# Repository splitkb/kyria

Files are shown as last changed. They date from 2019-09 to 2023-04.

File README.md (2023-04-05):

# Kyria

The Kyria is a split keyboard kit by Thomas Baart of [splitkb.com](https://splitkb.com). In this repository you'll find files you can use to make your own Kyria case.

THE SOFTWARE IS PROVIDED "AS IS", WITHOUT WARRANTY OF ANY KIND, EXPRESS OR IMPLIED, INCLUDING BUT NOT LIMITED TO THE WARRANTIES OF MERCHANTABILITY, FITNESS FOR A PARTICULAR PURPOSE AND NONINFRINGEMENT. IN NO EVENT SHALL THE AUTHORS OR COPYRIGHT HOLDERS BE LIABLE FOR ANY CLAIM, DAMAGES OR OTHER LIABILITY, WHETHER IN AN ACTION OF CONTRACT, TORT OR OTHERWISE, ARISING FROM, OUT OF OR IN CONNECTION WITH THE SOFTWARE OR THE USE OR OTHER DEALINGS IN THE SOFTWARE.

These files are available for non-commercial use only. You explicitly have permission to make objects with these files for yourself, friends, family and coworkers. If you'd like to sell objects made from these files, please [get in touch](mailto:support@splitkb.com?subject=Aurora%20case%20licensing).

## Which files do I need?

1. Look for the folder of your keyboard, depending on your revision.
2. Decide whether you need kerf (see below: What's kerf?).
3. Pick the files for your keyboard:
    - **A bottom plate**: We have normal plates and puck plates. A normal plate is a fully covered plate, whereas a puck plate is compatible with the splitkb.com [Tenting Puck](https://splitkb.com/products/tenting-puck). It has a circular slot cut out for the puck to sit into. Bottom plates can easily be replaced later, so feel free to get a normal plate if you don't have a puck yet.
    - **A top plate**: We have normal plates, no puck plates and encoder plates. Normal plates have mounting holes, holes for switches, and holes for the puck screws to be mounted through. I recommend getting the normal plates, as the extra holes don't impact functionality and make it easier to add a puck later. The "no puck" plates don't have these extra mounting holes, and the "encoder" plates have wider holes for when you want to use an encoder on a choc-based build. You'll likely want to modify the encoder files before using them, as an encoder hole is larger and won't allow a switch to clip into the plate.
    - **An OLED cover**: Most keyboards will support OLED covers. They protect the microcontroller and display area. Even if you don't use an OLED, I still recommend using a cover, as it'll make the keyboard look more finished. If your keyboard doesn't have a file with "OLED Cover" in its name, then a cover isn't supported.

For rev1 and rev2 boards, a high profile case is available. The case composition and required hardware is a little different there, and is not supported for rev3 for the time being.

All files are symmetrical, meaning you use the same file for both the left and the right side. When ordering parts, make sure you order two of every file you've selected.

The files in this repository are DXF files, which can be opened using a tool like LibreCAD, Adobe Illustrator or other similar CAD or graphic design software packages. You'll be able to send these to a manufacturer to produce cases with for personal use, or modify them using a tool like Fusion 360 to make your own 3D-printable cases.

## What's kerf?

Kerf is the amount of material that's lost in the process of cutting, for example with a laser or water jet. As the cutter moves along the lines in the file, material is removed from either side of the line. Files that account for kerf, add a little bit of material to the edges of all cut lines to compensate for that lost material.

In short, if you're using a laser cutter yourself, you'll want the files with kerf. If you're sending them off to another service, you should ask them whether to include kerf. And if you're 3D printing, you shouldn't need any kerf, or might even need to remove some extra material depending on your printer and calibration.

The files with kerf that we supply are used with our own laser cutter. Third parties might require different settings. We don't supply those files, so you or the third party may have to modify the files to match their process.

## Which thickness do I need?

It depends! Generally:

- For MX switches, 1.5mm is best for the top plate if the material is sturdy enough. For acrylic, go with 3mm.
- For Choc switches, 1.2mm is best for the top plate if the material is sturdy enough. 1.5mm is also fine, and in most cases this makes it compatible with both MX and Choc. For acrylic, go with 3mm and a hand-solderable kit. **Hot swapping 3mm plates makes for a bad experience.**
- For the bottom plate and OLED cover, thickness doesn't matter a lot. We usually go with 3mm for acrylic.

## Which hardware do I need?

The number and lengths of spacers and screws will depend on the keyboard, the switches you use, and the plate thicknesses you choose. You can get all the hardware and some extras when buying an [Aurora Hardware Kit](https://splitkb.com/products/aurora-low-profile-case-hardware-kit).

We also sell various hardware separately:

- [M2 spacers in various lenghts](https://splitkb.com/products/brass-m2-spacers)
- [M2 screws in various lenghts](https://splitkb.com/products/m2-screws)

Generally:

- For MX switches and a metal top plate, go with 8mm spacers.
- For MX switches and an acrylic top plate, go with 6mm spacers.
- For Choc switches and a metal top plate, go with 6mm spacers.
- For Choc switches and an acrylic top plate, go with 4mm spacers.

The OLED cover requires 12mm spacers when using a display, though you might get away with 10mm in some cases. If you don't use a display, you can use 8mm or maybe even 6mm spacers.

## What should I keep in mind?

To prevent disappointment, take care of the following:

- Make sure of some measurements beforehand. For files without kerf, the size of a switch hole will be exactly 14x14mm. For files with kerf, the size of a switch hole will be exactly 13.9x13.9mm.
- Only use plates thicker than 1.6mm with hand solder kits. Hot swapping with thick plates is a bad experience.
- Only use acrylic as a material with plates thicker than 2mm, preferably 3mm. Thin acrylic is fragile and is likely to break during assembly.
- Take care when ordering detoriable materials like copper or brass. They will oxidate over time, which can give a nice patina look when done, but results definitely vary. If you'd like to keep copper or brass nice, take care to wax or coat it, preferably every once in a while.
- When painting or coating plates, some material is added. You might want to enlarge the switch holes to compensate for added thickness paint may add.

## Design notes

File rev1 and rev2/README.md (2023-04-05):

## High Profile Case

The high profile case covers both the top, bottom and the sides. When cut from frosted acrylic, this provides a nicely diffused effect inc combination with underglow.

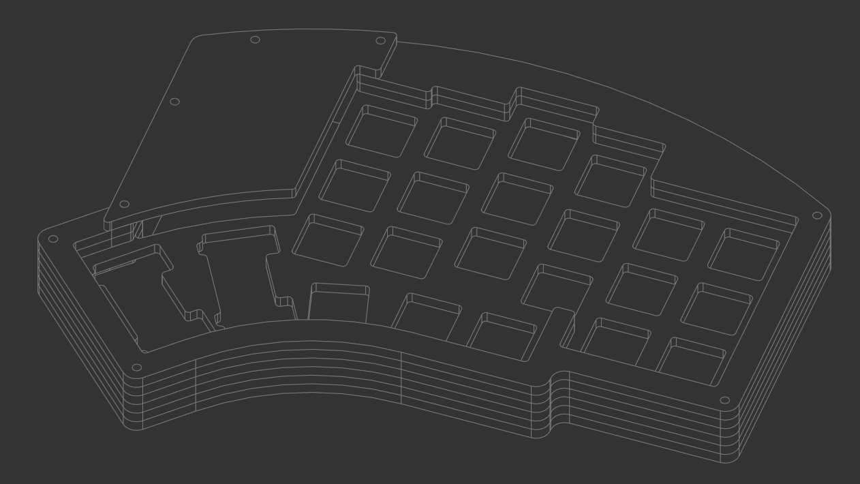
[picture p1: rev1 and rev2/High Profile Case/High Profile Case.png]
High Profile Case


## Plate Case

The plate case is an option which covers just the PCB and nothing more. Great if you desire a lower weight or a lower price.

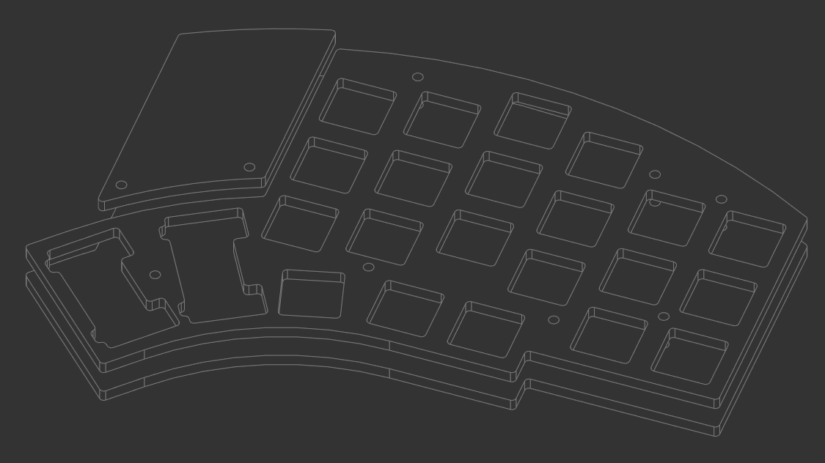
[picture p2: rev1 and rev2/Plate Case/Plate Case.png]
Plate Case


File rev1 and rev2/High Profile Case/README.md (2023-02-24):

Kyria Acrylic High Profile Case
===============================

This is a case for the Kyria, compatible with revision 0.7 - 2.1. **It is not compatible with revision 3.0 and up** - files for revision 3 will be released later.

Kyria Acrylic High Profile Case

This case supports MX switches only. A plate is also available for ALPS switches, though that doesn't support the tenting puck.

To make a case, you'll need to cut the following out of 3mm thick acrylic:

- 2 × Bottom
- 4 × Mid
- 2 × Plate
- 2 × Top 1
- 2 × Top 2
- 2 × Guard

Alternatively when not using OLED displays, you can cut 2 × Integrated Guard instead of 2 × Top 2 and 2 × Guard.

Furthermore, you'll need:

- 36 × 8mm M2 machine screw
- 18 × 10mm M2 round spacer

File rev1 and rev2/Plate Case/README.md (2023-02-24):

Kyria Acrylic Plate Case
========================

This is a case for the Kyria, compatible with revision 0.7 - 2.1. **It is not compatible with revision 3.0 and up** - files for revision 3 will be released later.

Kyria Acrylic Plate Case

This case supports MX and Choc switches. A file for a plate that supports ALPS cases is also available, though it doesn't support the tenting puck.

To make a case, you'll need to cut the following files out of 3mm thick acrylic:

- 2 × Base
- 2 × Plate
- 2 × Guard

Furthermore, you'll need:

- 36 × 5mm M2 machine screw
- 14 × 6mm M2 round spacer
- 4 × 12mm M2 round spacer

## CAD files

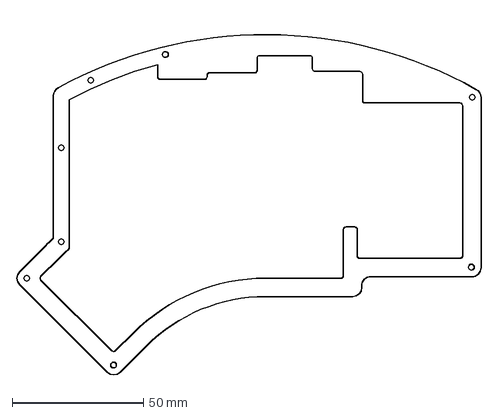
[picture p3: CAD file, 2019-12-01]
High Profile Case/0.10mm Kerf/05 Hi pro 2.dxf
177.0 x 136.9 mm

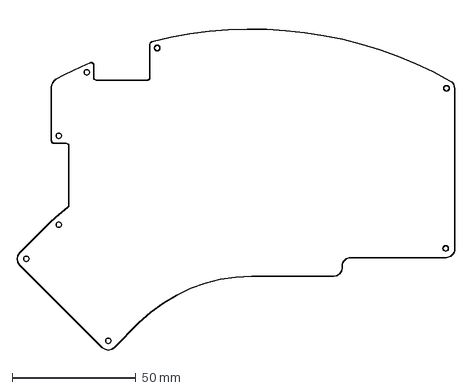
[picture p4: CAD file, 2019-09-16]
High Profile Case/01 Base.dxf
177.0 x 135.2 mm

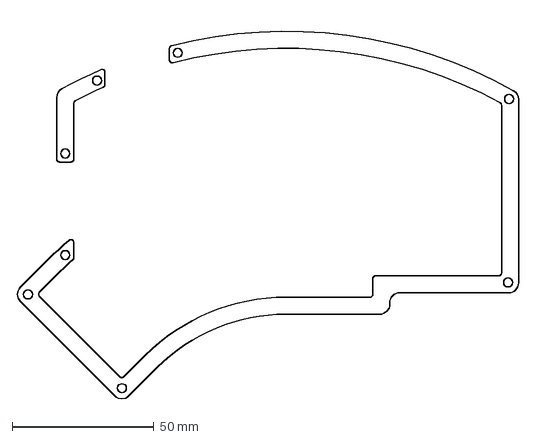
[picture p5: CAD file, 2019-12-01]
High Profile Case/No Kerf/02 Mid.dxf
177.0 x 135.2 mm

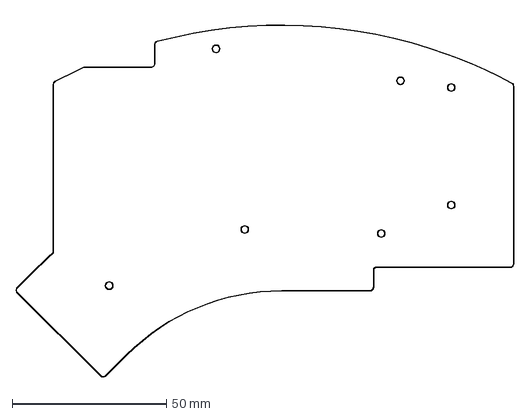
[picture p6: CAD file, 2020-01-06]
Plate Case/0.15mm Kerf/01 Base.dxf
161.1 x 116.9 mm

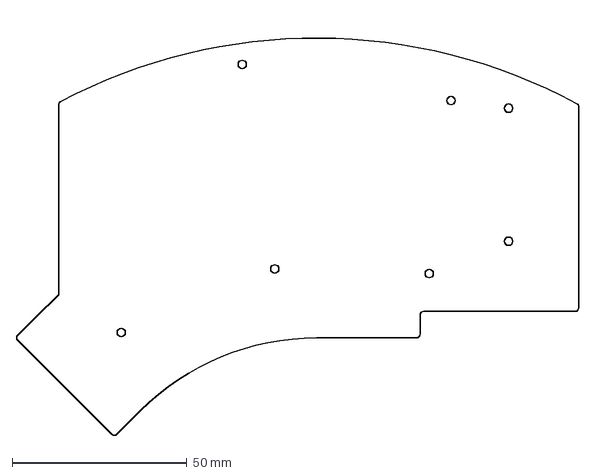
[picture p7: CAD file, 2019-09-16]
Plate Case/01 Base.dxf
160.9 x 120.0 mm

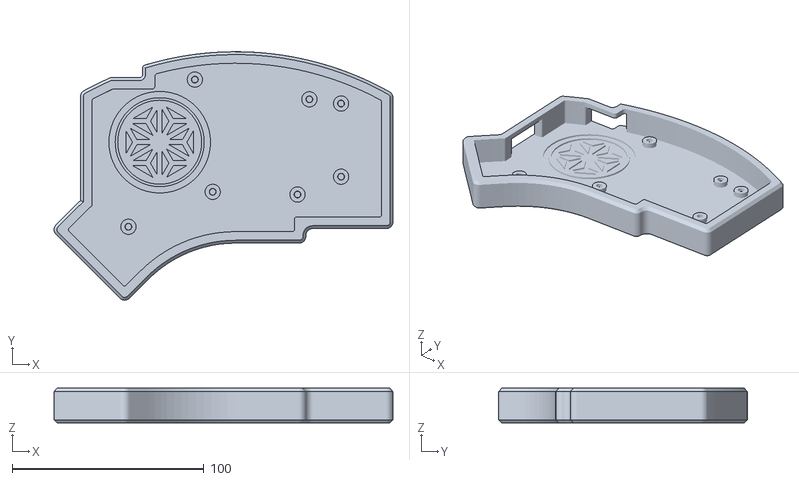
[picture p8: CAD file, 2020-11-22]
rev1 and rev2/3D Printed Case/case files/kyria_logo_right_case.stl
176.7 x 129.5 x 18.0

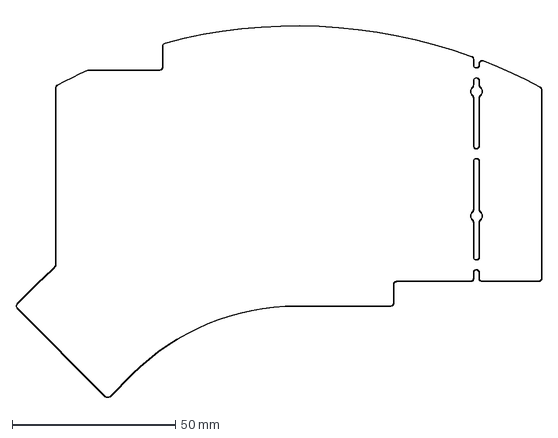
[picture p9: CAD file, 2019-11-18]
rev1 and rev2/Edge Cuts.dxf
160.9 x 116.7 mm

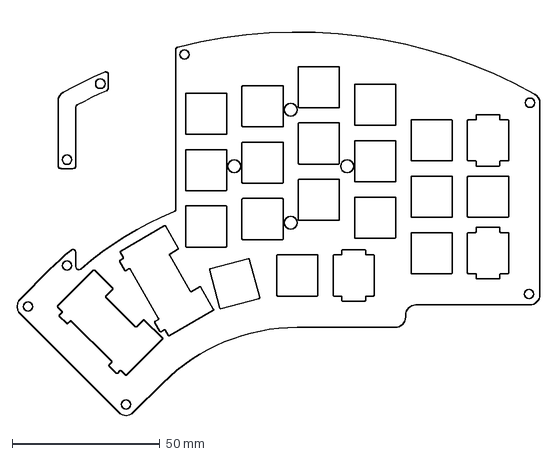
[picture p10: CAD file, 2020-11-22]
rev1 and rev2/High Profile Case/Kyria HiPro Case Plate - 0.1mm Kerf.dxf
177.0 x 135.2 mm

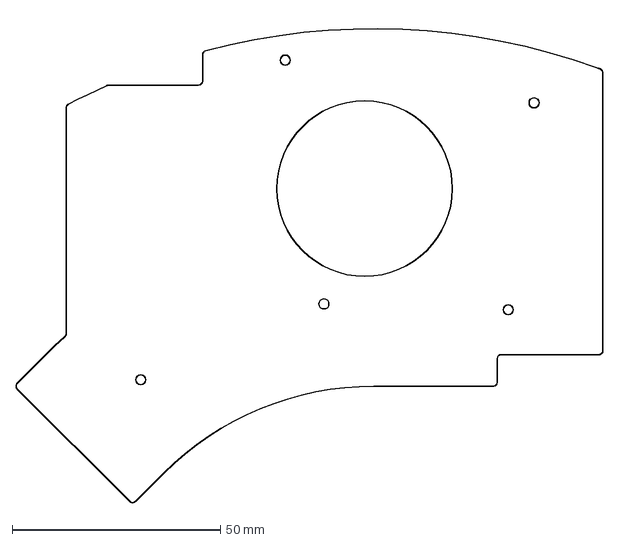
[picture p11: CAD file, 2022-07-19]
rev1 and rev2/Plate Case/Kyria Plate Case Bottom - 5 columns - Puck - 0.1mm Kerf.dxf
140.7 x 116.6 mm

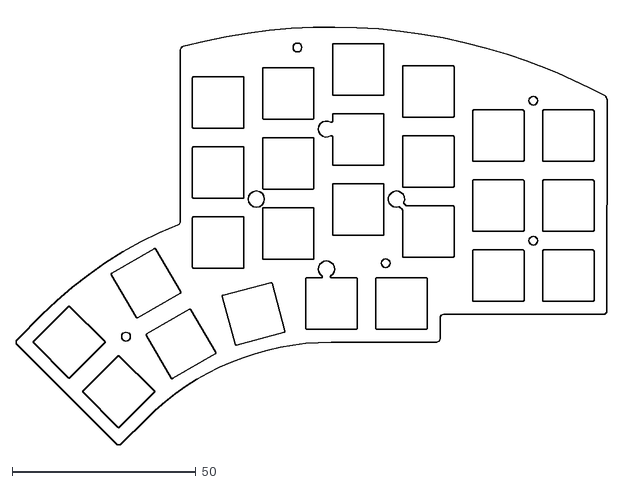
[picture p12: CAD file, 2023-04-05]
rev3/Kyria rev3 Top Plate - No Kerf.dxf
160.8 x 116.6

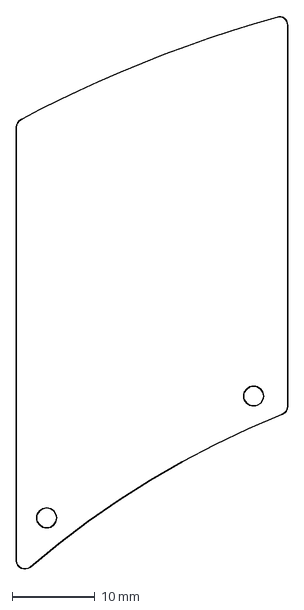
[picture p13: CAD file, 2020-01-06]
Plate Case/0.15mm Kerf/03 Guard.dxf
32.8 x 66.8 mm

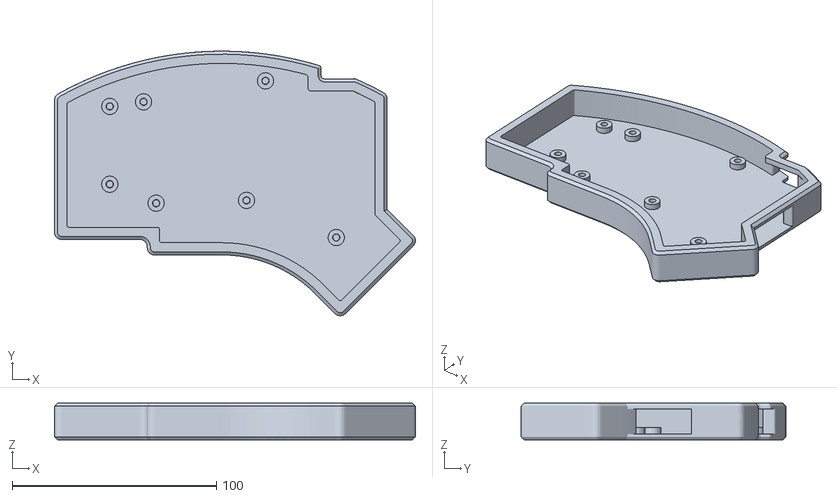
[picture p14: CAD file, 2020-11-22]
rev1 and rev2/3D Printed Case/case files/left_case.stl
176.7 x 129.5 x 18.0

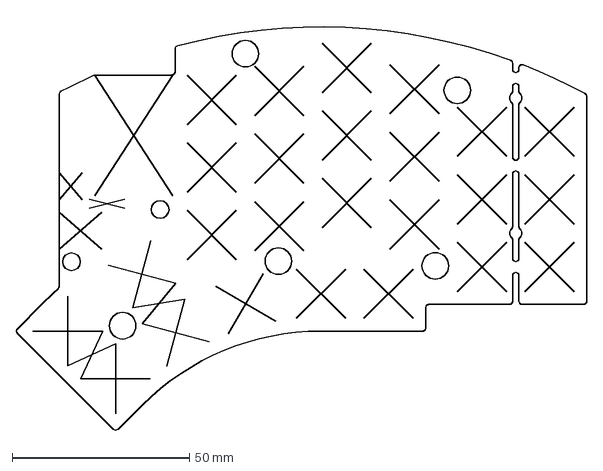
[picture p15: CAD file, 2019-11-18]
rev1 and rev2/Key Positions.dxf
160.9 x 116.7 mm

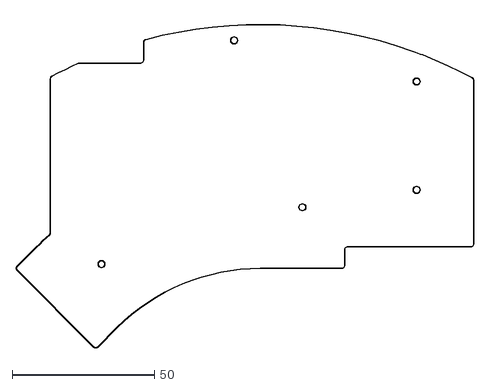
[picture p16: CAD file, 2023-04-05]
rev3/Kyria rev3 Bottom Plate - No Kerf.dxf
160.8 x 116.6

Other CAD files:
High Profile Case/0.10mm Kerf/04 Hi pro 1.dxf
High Profile Case/02 Mid.dxf
High Profile Case/04 Hi pro 1.dxf
High Profile Case/05 Hi pro 2.dxf
High Profile Case/No Kerf/04 Hi pro 1.dxf
Plate Case/0.10mm Kerf/01 Base.dxf
Plate Case/0.10mm Kerf/03 Guard.dxf
Plate Case/No Kerf/01 Base.dxf
Plate Case/No Kerf/03 Guard.dxf
rev1 and rev2/3D Printed Case/case files/kyria_3d_case.f3d
rev1 and rev2/3D Printed Case/case files/right_case.stl
rev1 and rev2/3D Printed Case/case files/switch_plate.stl
rev1 and rev2/High Profile Case/Kyria HiPro Case Base - No Puck - 0.1mm Kerf.dxf
rev1 and rev2/High Profile Case/Kyria HiPro Case Base - No Puck - No Kerf.dxf
rev1 and rev2/High Profile Case/Kyria HiPro Case Base - Puck - 0.1mm Kerf.dxf
rev1 and rev2/High Profile Case/Kyria HiPro Case Base - Puck - No Kerf.dxf
rev1 and rev2/High Profile Case/Kyria HiPro Case Mid - 0.1mm Kerf.dxf
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

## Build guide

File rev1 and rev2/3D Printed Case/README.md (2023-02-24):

Kyria 3D Printed Case
========================

This is a 3D printed case for the Kyria, compatible with revision 0.7 - 2.1. **It is not compatible with revision 3.0 and up** - files for revision 3 will be released later.

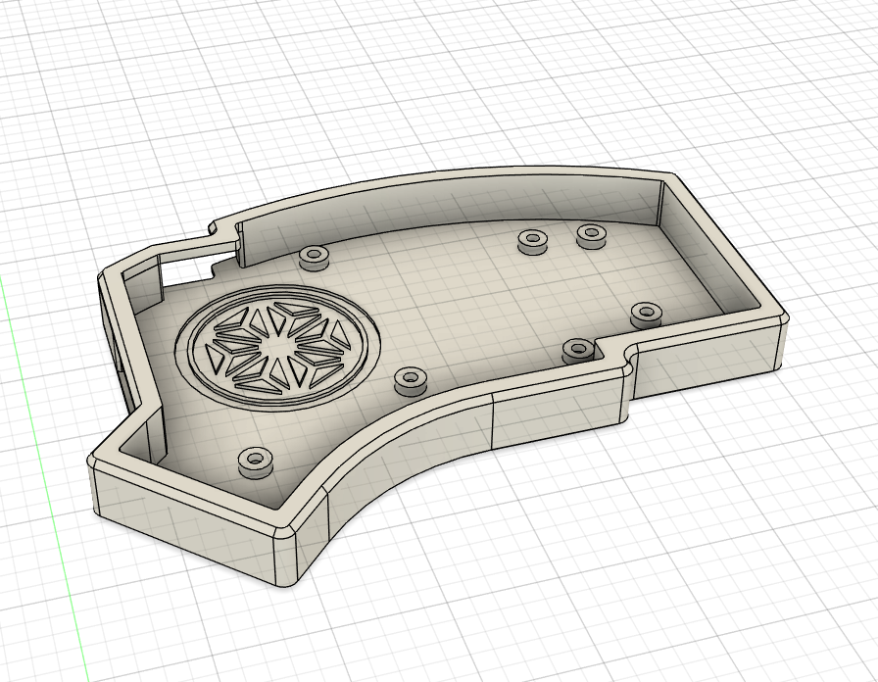
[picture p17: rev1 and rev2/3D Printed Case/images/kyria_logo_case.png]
Kyria Acrylic Plate Case


To make a case, you'll need to print:

- left_case.stl
- right_case.stl or kyria_logo_right_case.stl

Furthermore, you'll need:

- 14 of M2 x 10mm machine screws
- 14 of M2 tapered heat-set inserts *(the ones used in the example photos below [Link](https://www.mcmaster.com/94180A312))*
- 2 x switch plates

This case is designed to work with the same sized plate as the one in the "Plate Case". A STL to 3D print a plate is provided in the case files, but a laser cut metal or acryllic plate can also be used.

## Assembly
- Heat-set inserts should be slowly pressed into each "pillar" with the tip of a soldering iron set at the same temperature as your 3D printer nozzle temperature.
- Plate/PCB are mounted to the case body with screws going through both Plate and PCB, tightening onto the top of the switch plate to hold it firmly into the case. 

**Screws should be firm but not overtightened**

## Build Photos
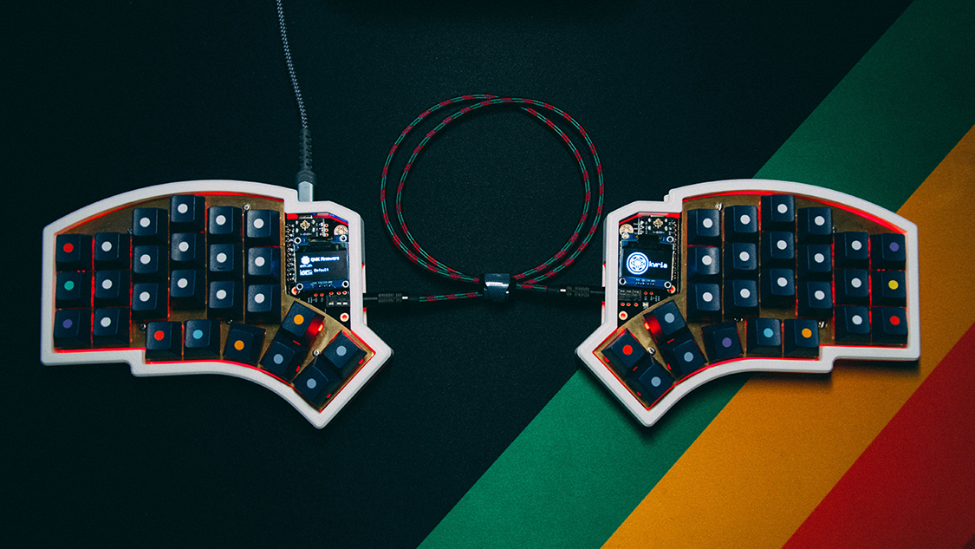
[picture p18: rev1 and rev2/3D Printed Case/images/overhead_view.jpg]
Left Case

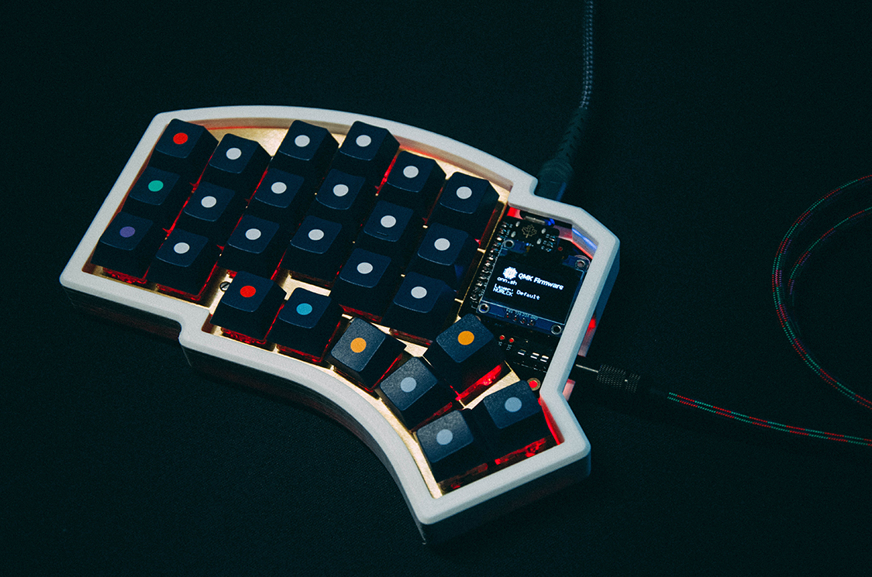
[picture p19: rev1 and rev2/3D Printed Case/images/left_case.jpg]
Left Case

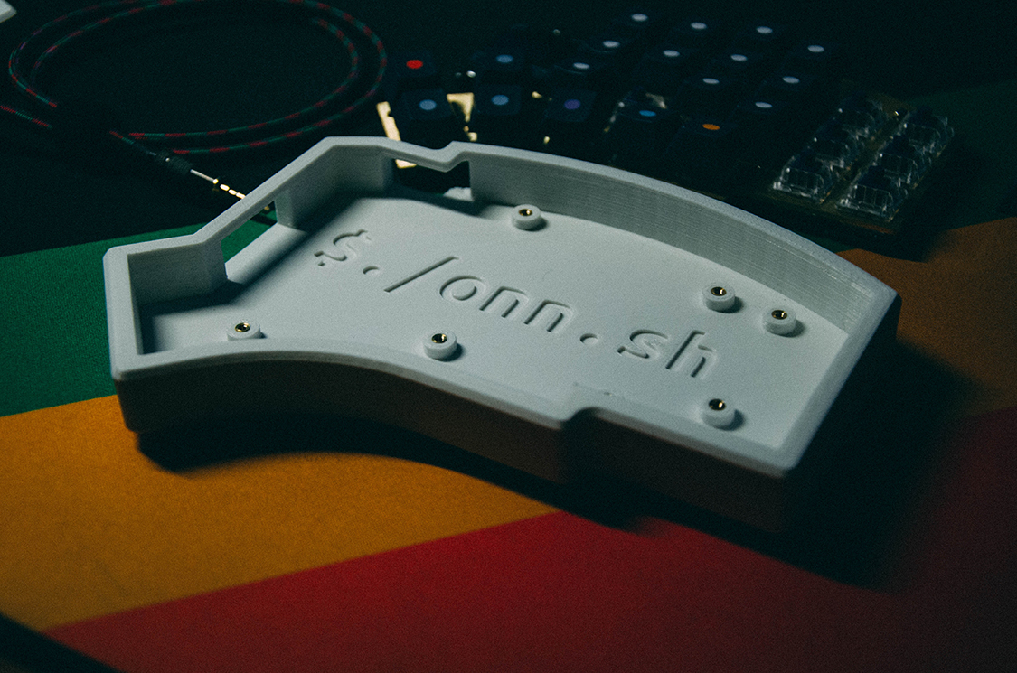
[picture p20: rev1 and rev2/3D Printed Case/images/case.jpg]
Left Case

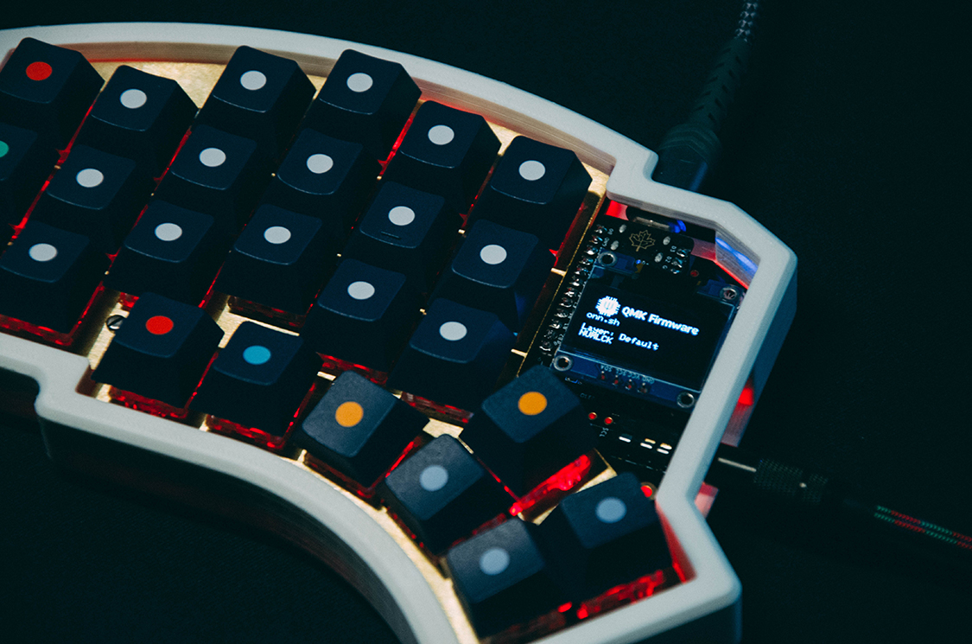
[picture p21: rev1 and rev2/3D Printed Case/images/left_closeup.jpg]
Left Case

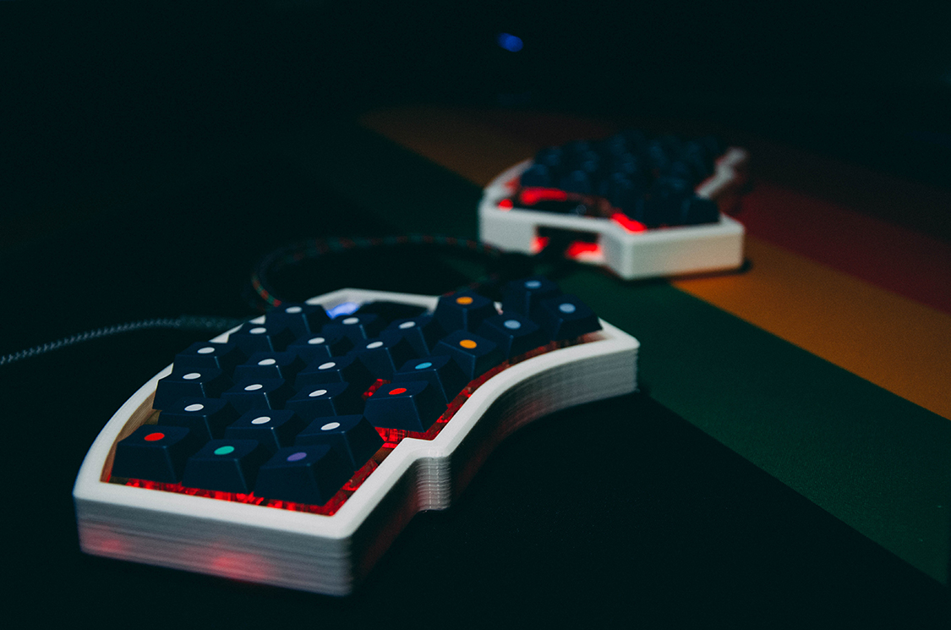
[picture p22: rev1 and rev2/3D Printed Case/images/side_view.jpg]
Left Case


*Case Designed 2020 by Stephen Onnen*

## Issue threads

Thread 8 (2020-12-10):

Missing file for bottom plate, 6 col, without puck, with kerf

timtraversy, 2020-12-10:
Hello,

Thanks for all the awesome work here. I'm planning on cutting the Plate Case, but it seems like one of the files is missing.

For the bottom plate, there seem to be 3 variables: Columns, Puck, Kerf. Every permutation of these is represented except:

- 6 Columns
- No Puck
- 0.1 mm Kerf

Do you have that file?

Thanks very much,
Tim

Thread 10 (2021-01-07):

Missing files: Kyria HiPro Case Plate, No Puck

LuisMorenoSerrano, 2021-01-07:
Latest versions of **Kyria HiPro Case Plate** (_0.1mm Kerf_ and _No Kerf_) are **Puck versions** both. I would like to have **No Puck** versions too, but I have no software for making this kind of change.

Thanks a lot for your impressive work, regards.

silverbluep, 2021-01-07:
@LuisMorenoSerrano you can check commit history; the previous files are the no-puck versions.

LuisMorenoSerrano, 2021-01-07:
You are right @silverbluep, thanks for the advice. I have downloaded deleted file (no puck version) but, apart of new holes, it is not exactly the same as latest version... Finally I have manually edited latest version and I removed the new four circles, so now I have a no puck version :)

Regards

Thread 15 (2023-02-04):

PCB files missing

tim-hilt, 2023-02-04:
Hi there! I am literally building an Aurora Corne that I ordered from you right now. I really enjoyed your service and the fast delivery to Germany.

I would like to build a Kyria next and wanted to take a stab at ordering PCBs myself. Are you seeing yourself releasing the Gerber-files on here anytime soon?

The Kyria is an awesome layout and I‘d understand if open-sourcing is not an option from a business-standpoint.

splitkb, 2023-02-04:
The PCB files are deliberately not open source, in order to support our livelihood :) Thank you for your interest!

tim-hilt, 2023-02-04:
Makes total sense. Thanks for the response though! I'll order it from you then :D

Closed 2023-02-04.

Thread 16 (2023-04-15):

No Encoder cutouts on Rev3 Top Plates

DreamShark-Bytes, 2023-04-15:
All 4 files for Rev3's Top Plates don't have Encoder cutouts.
1. Kyria rev3 Top Plate - 0.1mm Kerf.dxf
2. Kyria rev3 Top Plate - No Kerf
3. Kyria rev3 Top Plate - No Puck - 0.1mm Kerf.dxf
4. Kyria rev3 Top Plate - No Puck - No Kerf.dxf

Here is an example of one file:
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

thomasbaart, 2023-04-28:
That is correct. Since the rev3 has hotswap capabilities, you'll want to add the cutouts yourself. Adding cutouts to all positions by default would make switches on those locations wobbly.

It's not an ideal solution, but I think it's the best compromise.

autoferrit, 2023-05-22:
can this be done at all with the splitkb kit version if we want to use choc switches? would like to be able to use encoders with it.

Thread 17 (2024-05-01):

Is this where we can put suggestions for Rev4?

IndianBoy42, 2024-05-01:
Hey, I'm a very happy kyria user for 2 years who has started to think about going even more ergo: tenting and all that. But I've been wishing that the thumb cluster could be at a different angle (dactyl manuform style). Is it feasible that in Rev4 the thumb cluster is separable, similar to the way that last column is, but with the contacts or a port so it can be reconnected and still function. Then the case mounts the 2 pcbs at separate angles

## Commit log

2019-09-16 Added high profile acrylic case files
    [01 Base.dxf, 02 Mid.dxf, 03 Plate.dxf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]
2019-09-16 Notes Kyria High Profile Case switch compatibility
2019-09-16 Added plate style case, case images
    [01 Base.dxf, 02 Plate.dxf, 03 Guard.dxf]
2019-10-16 Added ALPS compatible High Profile plate
    [03 Plate ALPS.dxf]
2019-11-18 Added edge cuts and key position files
    [Edge Cuts.dxf, Key Positions.dxf]
2019-12-01 Added kerf variants and ALPS plates
    [01 Base.dxf, 02 Mid.dxf, 02 Plate ALPS.dxf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]
2020-01-06 Added 0.15mm Kerf Plate Case files
    [01 Base.dxf, 02 Plate ALPS.dxf, 02 Plate.dxf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]
2020-02-05 Updated plate case readme
    Both MX and Choc are compatible
2020-05-20 Updated readme, added f3d file
    [kyria_3d_case.f3d]
2020-05-20 Updated readme to provide more assembly details
2020-11-22 Updated case files and readme: support added for tenting puck accessory, integrated OLED guard for hipro case
    [01 Base.dxf, 02 Plate ALPS.dxf, 02 Plate.dxf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]
2021-08-05 feat(tenting-puck): add puck kicad footprint
2022-07-19 Update 5 column plate case
    [Kyria Plate Case Bottom - 5 columns - Puck - 0.1mm Kerf.dxf, Kyria Plate Case Bottom - 5 columns - Puck - No Kerf.dxf, Kyria Plate Case Top - 5 columns - 0.1mm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]
2023-04-05 Add rev3 low profile case, restructure file tree
    [Edge Cuts.dxf, Key Positions.dxf, Kyria HiPro Case Base - No Puck - 0.1mm Kerf.dxf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]
